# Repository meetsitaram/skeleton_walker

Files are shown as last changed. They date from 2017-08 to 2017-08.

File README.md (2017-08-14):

# Spider Hexapod

- Body designed and 3D printed
- Leg joint lengths set based on torque limits
- Servos positions have been callibrated
- Walks by 3 leg gait
 
# First Walk
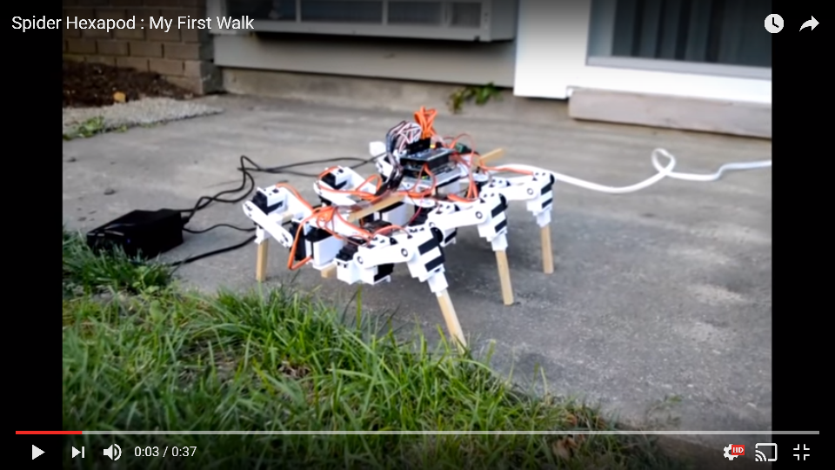
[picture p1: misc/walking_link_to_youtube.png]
First Walk (https://www.youtube.com/watch?v=spd2VwvuzV0 "Spider Hexapod : My First Walk")


# Hexapod standing up and switching on three legs:
Hexapod

## Build
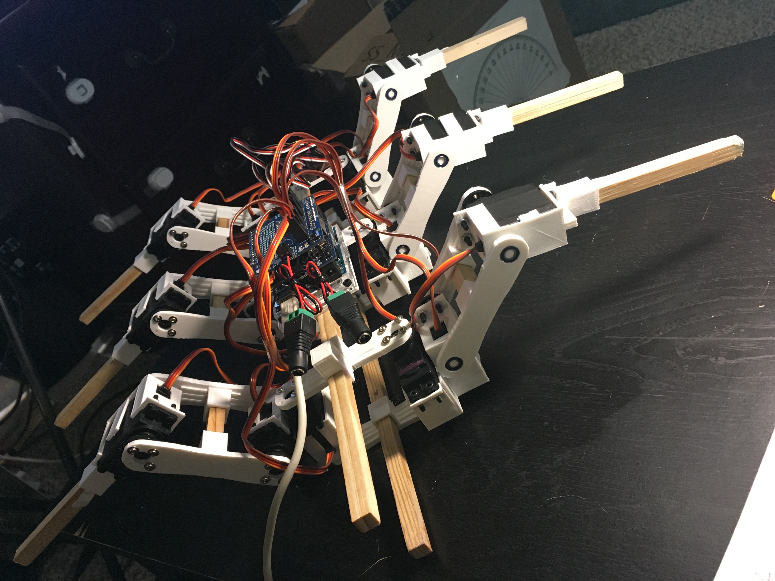
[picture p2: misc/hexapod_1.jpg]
Hexapod

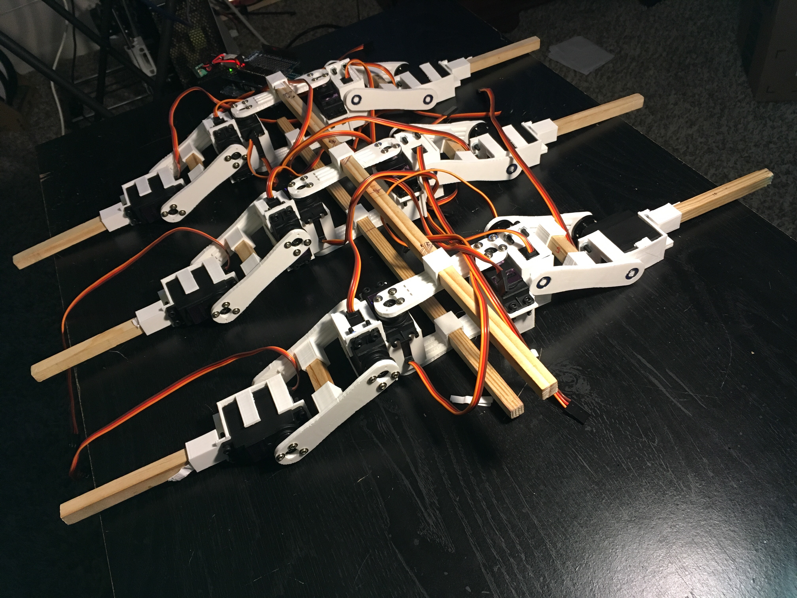
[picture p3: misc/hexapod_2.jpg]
Hexapod

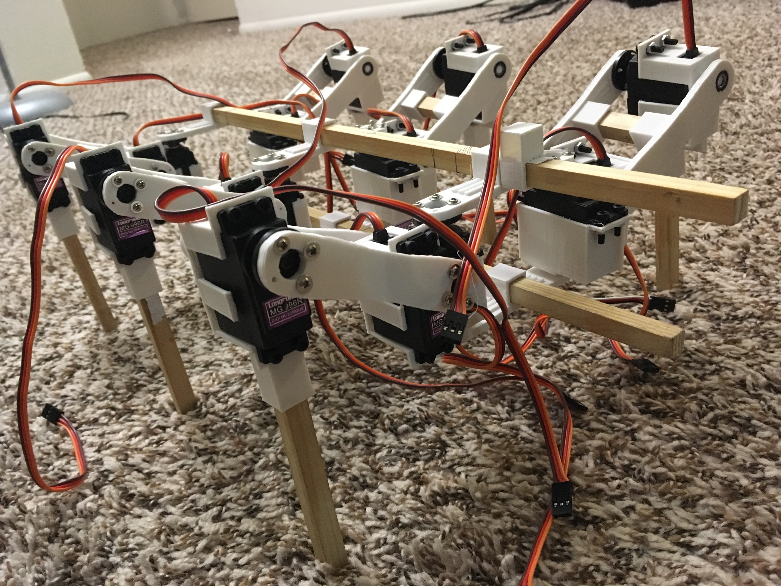
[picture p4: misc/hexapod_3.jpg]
Hexapod


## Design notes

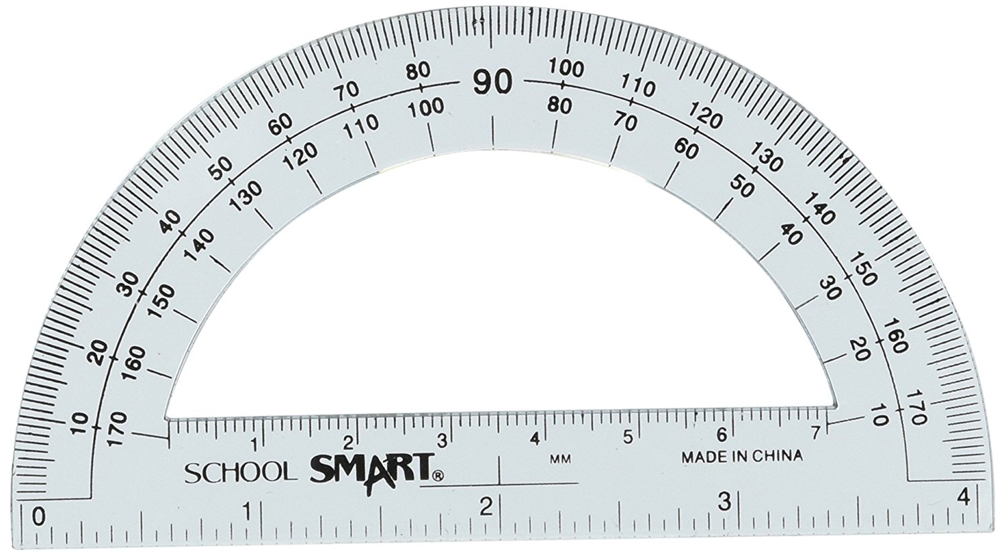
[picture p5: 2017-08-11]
docs/protractor.jpg

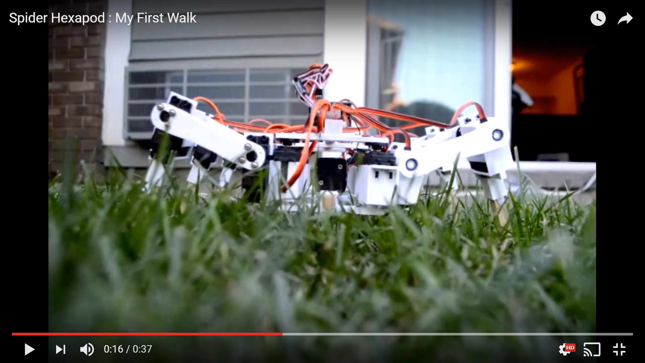
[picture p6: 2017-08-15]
misc/in_the_grass.jpg

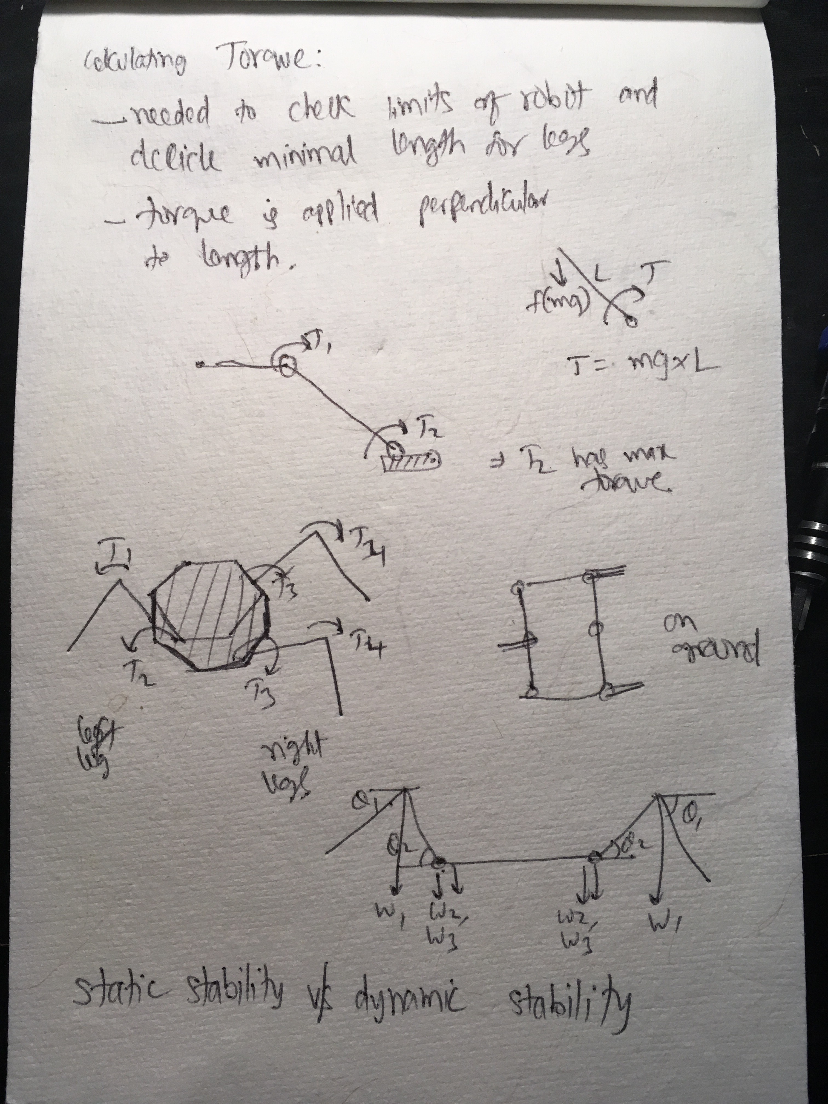
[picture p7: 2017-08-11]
misc/torque_calcs2.jpg

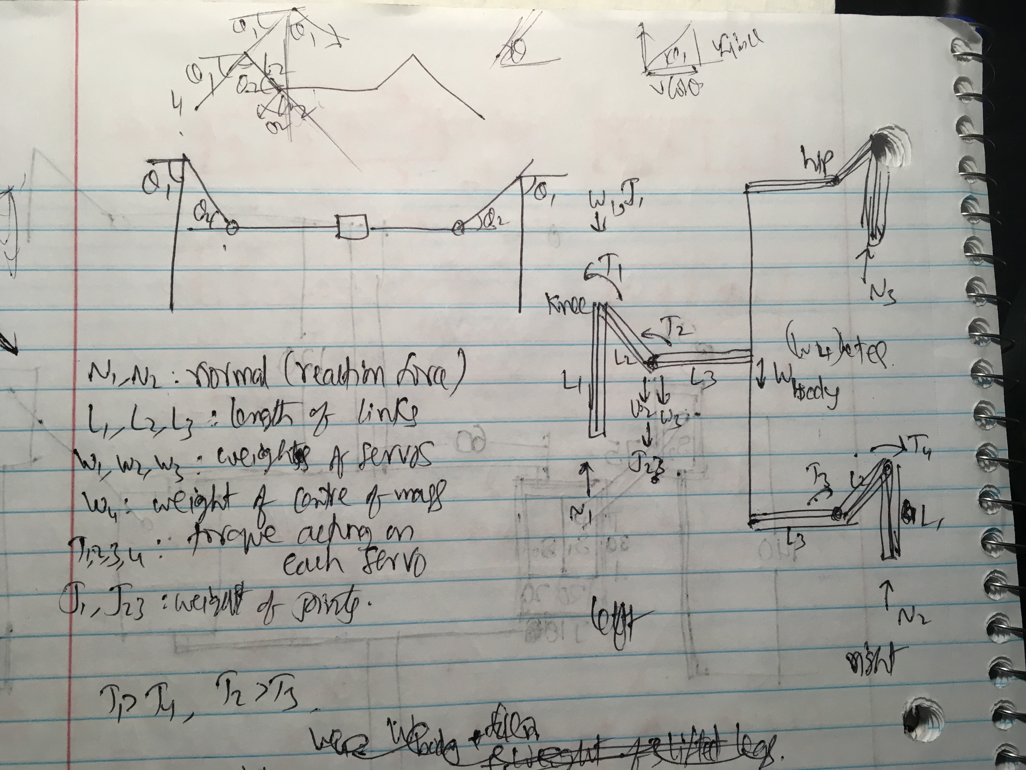
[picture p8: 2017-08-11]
misc/torque_calcs1.jpg

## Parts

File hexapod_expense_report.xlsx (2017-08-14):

$600, 150+ hours of effort and "lots" of patience
Part | Shopping Website | Amount | Qty | Total ($) | Part Description and Link
arduino | amazon | 19 | 1 | 19 | Arduino Uno R3 Microcontroller A000066 (https://www.amazon.com/gp/product/B008GRTSV6/ref=oh_aui_detailpage_o09_s00?ie=UTF8&psc=1)
servo shield | amazon | 16 | 2 | 32 | 2 of Adafruit 16-Channel 12-bit PWM/Servo Shield - I2C interface - (https://www.amazon.com/gp/product/B00I4WMOGE/ref=oh_aui_detailpage_o09_s00?ie=UTF8&psc=1)
hex bolts (100) | amazon | 17 | 1 | 17 | M3 x 12 Hex Bolt Socket Head Cap Machine Screws Black 100 Pcs (https://www.amazon.com/gp/product/B00W97N9X2/ref=oh_aui_detailpage_o03_s00?ie=UTF8&psc=1)
hex nut (100) | amazon | 5 | 1 | 5 | 100Pcs M3 3mm Female Thread Hex Metal Nut Fastener Silver Tone (https://www.amazon.com/gp/product/B00GYS1SXU/ref=oh_aui_detailpage_o02_s00?ie=UTF8&psc=1)
stackable headers | amazon | 7 | 1 | 7 | 2 of Arduino Stackable Header Kit - R3 (https://www.amazon.com/gp/product/B00PCCWEJG/ref=oh_aui_detailpage_o00_s00?ie=UTF8&psc=1)
right angle headers | amazon | 6 | 1 | 6 | Adafruit 3x4 Right Angle Male Header - 4 pack [ADA816] (https://www.amazon.com/gp/product/B00NAY2894/ref=oh_aui_detailpage_o09_s00?ie=UTF8&psc=1)
ball bearings | amazon | 10 | 2 | 20 | Traxxas 5116 5x11x4mm Replacement Precision Ball Bearings MR115-2RSBU (10) (https://www.amazon.com/gp/product/B00Y5W3JYS/ref=oh_aui_detailpage_o04_s00?ie=UTF8&psc=1)
servos (10x) | amazon | 47 | 2 | 94 | Longruner 10 x MG996R Metal Gear Torque Digital Servo Motor For RC Model Car Boat Helicopter LKY62 (https://www.amazon.com/gp/product/B01MTW06IU/ref=oh_aui_detailpage_o00_s00?ie=UTF8&psc=1)
servo extension wire (10) | amazon | 8 | 2 | 16 | 2 of Hobbypark 15cm Male to Female Servo Extension Lead Wire Cable for KK MWC Control Board RC Parts (Pack of 10) (https://www.amazon.com/gp/product/B01FLHLKZ0/ref=oh_aui_detailpage_o08_s00?ie=UTF8&psc=1)
DIY anet a8 3d printer | gearbest | 170 | 1 | 170 | Anet A8 Desktop 3D Printer Prusa i3 DIY Kit (http://www.gearbest.com/3d-printers-3d-printer-kits/pp_343643.html)
pla plastic | amazon | 22 | 1 | 22 | HATCHBOX 3D PLA-1KG1.75-WHT PLA 3D Printer Filament, Dimensional Accuracy +/- 0.05 mm, 1 kg Spool, 1.75 mm, White (https://www.amazon.com/gp/product/B00J0GMMP6/ref=oh_aui_detailpage_o01_s00?ie=UTF8&psc=1)
spool stable | amazon | 9 | 1 | 9 | Anycubic 1 Spool Stable Acrylic 3D Printer Filament Tabletop Mount Rack (https://www.amazon.com/gp/product/B019TRKDTC/ref=oh_aui_detailpage_o01_s00?ie=UTF8&psc=1)
print surface | amazon | 20 | 1 | 20 | BuildTak 3D Printing Build Surface, 6.5" x 6.5" Square, Black (Pack of 3) (https://www.amazon.com/gp/product/B00MN5X304/ref=oh_aui_detailpage_o00_s00?ie=UTF8&psc=1)
wooden dowel | home depot | 1.41 | 4 | 5.64 | Waddell 36 in. x 3/8 in. Hardwood Square Dowel (http://www.homedepot.com/p/Waddell-36-in-x-3-8-in-Hardwood-Square-Dowel-8306U/100534453)
hacksaw | home depot | 4 | 1 | 4 | Husky 6 in. Junior Hacksaw (http://www.homedepot.com/p/Husky-6-in-Junior-Hacksaw-122JHSC/204748808)
Clamp | home depot | 5 | 2 | 10 | BESSEY 4 in. x 2 in. Bar Clamp (http://www.homedepot.com/p/BESSEY-4-in-x-2-in-Bar-Clamp-LM2-004/204957893)
screw driver set | amazon | 14 | 1 | 14 | Oria 58-in-1 Precision Screwdriver Set with 54 Magnetic Bits for all Electronics Devices
soldering kit | amazon | 33 | 1 | 33 | Sywon Full Set 60W 110V Electric Soldering Iron Kit with Adjustable Temperature Welding Iron, 5pcs Tips, Desoldering Pump, 2pcs Tweezers, Tin Wire Tube, Stand and 6pcs Aid Tools in PU Carry Bag (https://www.amazon.com/gp/product/B01E1ISGH0/ref=oh_aui_detailpage_o04_s01?ie=UTF8&psc=1)
Multimeter | amazon | 19 | 1 | 19 | 2 of INNOVA 3320 Auto-Ranging Digital Multimeter (https://www.amazon.com/gp/product/B000EVYGZA/ref=oh_aui_detailpage_o05_s00?ie=UTF8&psc=1)
desoldering wick | amazon | 4 | 1 | 4 | Aven 17542 Desoldering Wick, 2.5mm Width, 5' Length (https://www.amazon.com/gp/product/B003E48ERU/ref=oh_aui_detailpage_o05_s00?ie=UTF8&psc=1)
solder wire | amazon | 9 | 1 | 9 | Sywon 60-40 Rosin Core Spool Solder Wire 0.039’’ 0.11lb (https://www.amazon.com/gp/product/B01LVTTL9E/ref=oh_aui_detailpage_o04_s01?ie=UTF8&psc=1)
6v battery pack | amazon | 11 | 1 | 11 | Tenergy 6V 2000mAh NiMH RX Battery Packs with Hitec Connector for Model Airplanes, RC Aircrafts, and Walking Robot (https://www.amazon.com/gp/product/B001BCOWLY/ref=oh_aui_detailpage_o00_s00?ie=UTF8&psc=1)
6v battery charger | amazon | 16 | 1 | 16 | Tenergy 6V-12V Universal Battery Pack Charger for NiMH NiCd RC Car Batteries (https://www.amazon.com/gp/product/B003MXMJX8/ref=oh_aui_detailpage_o00_s00?ie=UTF8&psc=1)
power plug | amazon | 7 | 1 | 7 | OdiySurveil(TM) 5Pairs 2.1mm x 5.5mm Female Male DC Power Plug Terminal Adapter for CCTV Cameras (https://www.amazon.com/gp/product/B00W058HHQ/ref=oh_aui_detailpage_o01_s00?ie=UTF8&psc=1)
Tool Kit | home depot | 14 | 1 | 14 | Stalwart Multipurpose Car and Office Black Tool Kit (15-Piece) (http://www.homedepot.com/p/Stalwart-Multipurpose-Car-and-Office-Black-Tool-Kit-15-Piece-75-HT015/206531732)
 |  | total |  | 583.64
 |  | total - printer |  | 413.64

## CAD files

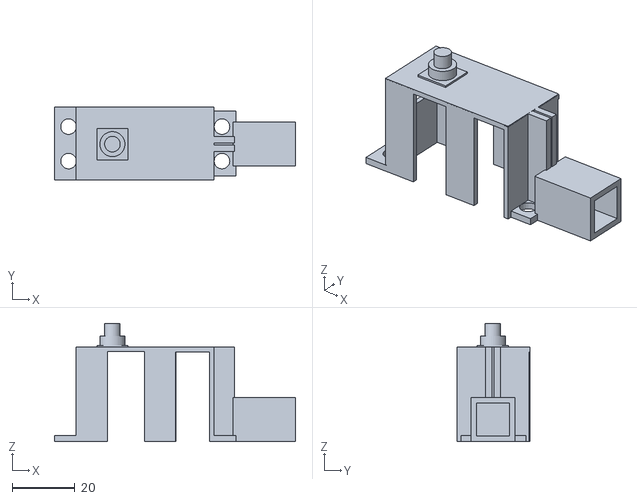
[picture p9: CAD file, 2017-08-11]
print3D/Clamp n Hold V2.stl
77.0 x 23.4 x 37.7

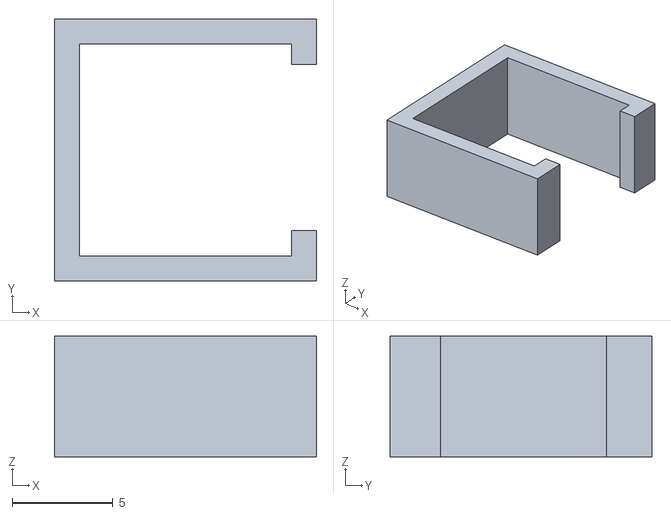
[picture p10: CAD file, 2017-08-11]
print3D/uno_support_clip.stl
13.0 x 13.0 x 6.00

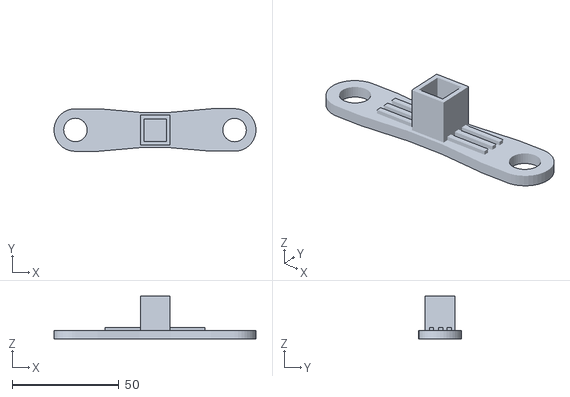
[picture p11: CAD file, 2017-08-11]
print3D/Leg Joint Th_b.stl
94.8 x 20.1 x 20.0

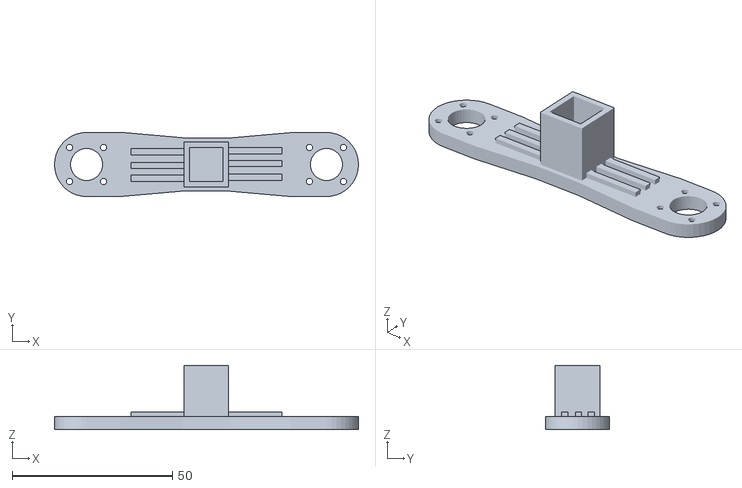
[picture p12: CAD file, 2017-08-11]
print3D/Leg Joint Th_a.stl
94.8 x 20.0 x 20.0

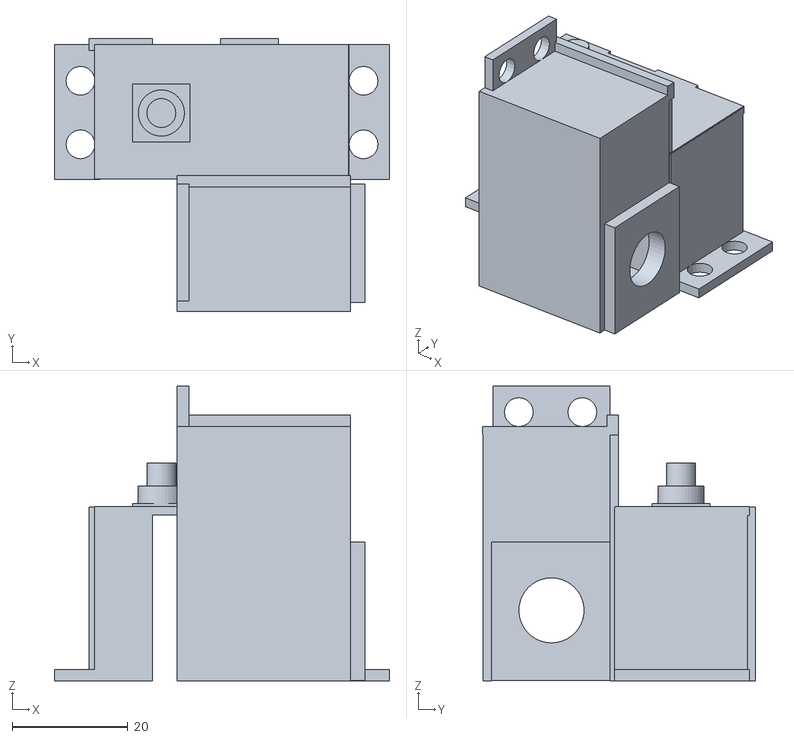
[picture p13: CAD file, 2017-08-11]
print3D/Servo Servo Clamp V4.1.stl
58.0 x 47.2 x 51.0

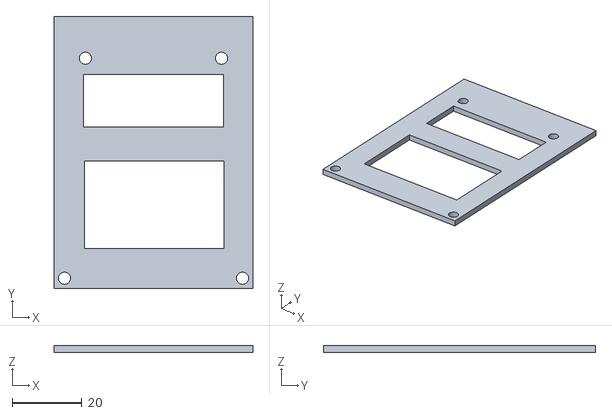
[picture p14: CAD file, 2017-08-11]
print3D/uno_support.stl
57.0 x 78.0 x 2.00

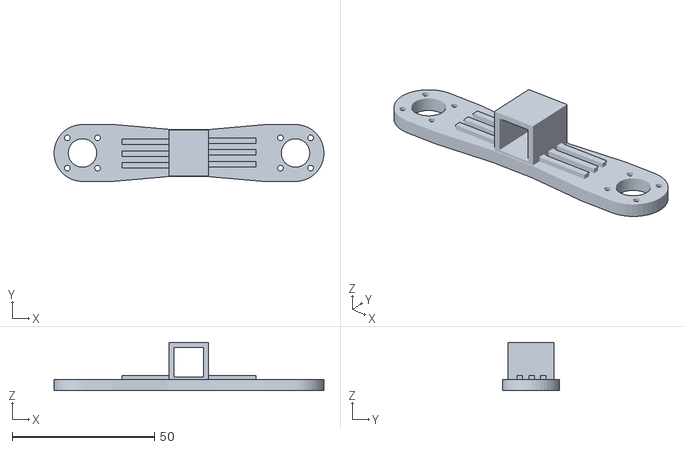
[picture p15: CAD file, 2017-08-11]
print3D/Frame Joint a.stl
94.8 x 20.0 x 17.0

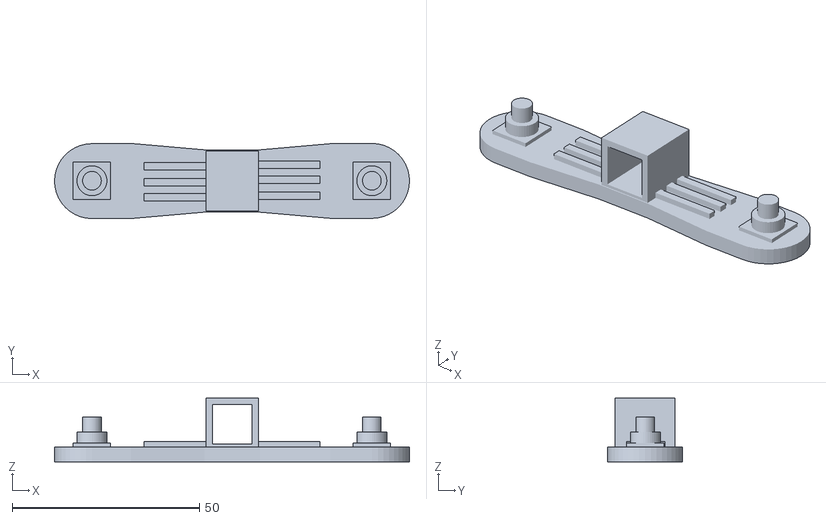
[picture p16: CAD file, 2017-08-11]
print3D/Frame Joint b.stl
94.8 x 20.1 x 17.0

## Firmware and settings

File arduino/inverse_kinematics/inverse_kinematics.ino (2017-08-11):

/*************************************************** 
  This is an example for our Adafruit 16-channel PWM & Servo driver
  Servo test - this will drive 16 servos, one after the other

  Pick one up today in the adafruit shop!
  ------> http://www.adafruit.com/products/815

  These displays use I2C to communicate, 2 pins are required to  
  interface. For Arduino UNOs, thats SCL -> Analog 5, SDA -> Analog 4

  Adafruit invests time and resources providing this open source code, 
  please support Adafruit and open-source hardware by purchasing 
  products from Adafruit!

  Written by Limor Fried/Ladyada for Adafruit Industries.  
  BSD license, all text above must be included in any redistribution
 ****************************************************/

#include <Wire.h>
#include <Adafruit_PWMServoDriver.h>
#include <math.h>

Adafruit_PWMServoDriver pwm = Adafruit_PWMServoDriver(0x40);
Adafruit_PWMServoDriver pwm2 = Adafruit_PWMServoDriver(0x41);

const double femur = 14.0; // in cm
const double tibia = 20.0;
const double coxa = 3.0; 
double Z_OFFSET = 0.0;

const int L_MIN = 15;
const int L_MAX = 12;


const int servoN10 = 0;
const int servoN10Min = 105;
const int servoN10Max = 480;
const int sheildN10 = 0;
const int initThetaN10 = 90;

const int servoN11 = 1;
const int servoN11Min = 85;
const int servoN11Max = 440;
const int sheildN11 = 0;
const int initThetaN11 = 0;
const int thetaOffsetN11 = 15;

const int servoN12 = 2;
const int servoN12Min = 95;
const int servoN12Max = 450;
const int sheildN12 = 0;
const int initThetaN12 = 0;
const int thetaN12Skew = 45.0; // servo's 0 pos is set at 45 degree angle

double getAlpha(double h, double f, double servoLift) {
  double L1 = sqrt(pow(h,2)+ pow(f,2));
  double z = Z_OFFSET + servoLift;
  double L = sqrt(pow(z,2) + pow(L1-coxa,2)); // L is radial dist from servo 2
                                                              // L1 is horizontal distance from center
  double alpha1 = acos(z/L);
  double alpha2 = acos( (pow(femur,2) + pow(L,2) - pow(tibia,2)) / (2.0*femur*L) );

  double alpha = 180*(alpha1 + alpha2) / M_PI;
  if (alpha == NAN)  {
    return 0;
  }
  return alpha;
}

double getBeta(double h, double f, double servoLift) {
  double L1 = sqrt(pow(h,2)+ pow(f,2));
  double z = Z_OFFSET + servoLift;
  double L = sqrt(pow(z,2) + pow(L1-coxa,2)); // L is radial dist from servo 2
                                                              // L1 is horizontal distance from center  
  if (L > femur + tibia) {
    return 0;
  }
  Serial.print("in beta, l:"); Serial.println(L);
  double beta = (180.0/M_PI)*acos( ( pow(femur,2) + pow(tibia, 2) - pow(L,2) )/(2.0*femur*tibia) );
  return beta;
}

double getGamma(double h, double f) {
  double L1 = sqrt(pow(h,2)+ pow(f,2));

  double gamma = 180.0*(acos( h / L1)) / M_PI;
  Serial.print("gamma val:"); Serial.println(gamma);
  if (gamma == NAN)  {
    return 90;
  }

  if(gamma > 180 || gamma < 0) {
    return 90;
  }

  if(f < 0) {
    gamma = 0 - gamma;
  }
  return gamma;
}


void setServoPosition(int servoNum, int theta) {

  if (theta < 0 || theta > 180) {
    Serial.println("invalid theta:" + theta);
    return;
  }

  int shieldNum = 0;
  int pos0 = -1;
  int pos180 = -1;
  int thetaOffset = 0.0;
  switch(servoNum) {
    case servoN10:
      pos0 = servoN10Min;
      pos180 = servoN10Max;
      shieldNum = 0;
      break;  
    case servoN11:
      pos0 = servoN11Min;
      pos180 = servoN11Max;
      thetaOffset = 15;
      shieldNum = 0;
      break;  
    case servoN12:
      pos0 = servoN12Min;
      pos180 = servoN12Max;
      shieldNum = 0;
      break;  

    default:
      Serial.println("invalid servo:" + servoNum );
      return;                                
  }

  if (pos0 < 0 || pos180 < 0) {
    Serial.println("invalid servo:" + servoNum);
    return;
  }

  if (theta < thetaOffset) {
    theta = thetaOffset;
  }
  double pulseLength = map(theta, 0, 180, pos0, pos180);
  if(shieldNum == 0) {
    pwm.setPWM(servoNum, 0, pulseLength);
  } else {
    pwm2.setPWM(servoNum, 0, pulseLength);
  }
  
}

void setup() {
  
  
  Serial.begin(9600);
  Serial.println("16 channel, dual shield, Servo test!");

  pwm.begin();
  pwm.setPWMFreq(50); 
  

  yield();
}

void setArmPosition(double h, double f, double servoLift) {
  double gamma = getGamma(h, f);
  Serial.print("gamma:"); Serial.println(gamma);
  Serial.print("90 - gamma:"); Serial.println(90 - gamma);
  
  double alpha = getAlpha(h, f, servoLift);
  Serial.print("180 - alpha:"); Serial.println(180 - alpha);

  double beta = getBeta(h, f, servoLift);
  Serial.print("beta:"); Serial.println(beta);

  setServoPosition(servoN10, 90 - gamma);
  setServoPosition(servoN11, 180 - alpha);
  setServoPosition(servoN12, beta - 45);  
}

void testMoveStraight() {
  double h = 20;  //horizontal distance from center
  //double f = -10; // forward or backward distance
  int servoLift = 8; // height of center above ground

  for(double f = 20.0; f >= -20; f = f-1) {
    setArmPosition(h, f, servoLift);
    delay(100);
  }
  
  for(double f = -20.0; f <= 20; f = f+1) {
    setArmPosition(h, f, servoLift);
    delay(100);
  }  
}

void testMoveSideways() {
  double f = 0;  //horizontal distance from center
  int servoLift = 8; // height of center above ground

  for(double h = 30.0; h >= 15; h = h-1) {
    setArmPosition(h, f, servoLift);
    delay(100);
  }
  
  for(double h = 15.0; h <= 30; h = h+1) {
    setArmPosition(h, f, servoLift);
    delay(100);
  }  
}


void testMoveUpwards() {
  double f = 0;  //horizontal distance from center
  double h = 25;
  int servoLift = 8; // height of center above ground

  for(double servoLift = 8.0; servoLift >= -20; servoLift = servoLift-1) {
    setArmPosition(h, f, servoLift);
    delay(1000);
  }
  
  for(double servoLift = -20.0; servoLift <= 8; servoLift = servoLift+1) {
    setArmPosition(h, f, servoLift);
    delay(1000);
  }  
}

void loop() {

    testMoveStraight();
    testMoveSideways();
    //testMoveUpwards();

  

  delay(4000);

}

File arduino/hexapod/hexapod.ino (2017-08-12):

//
// Hexapod Code
//

#include <math.h>
#include "core_servo_utils.h"
#include "hexapod.h"

#include "walking_style.h"

WalkingStyle style;
bool ENABLE_DEBUG = false;

void setup() {
  
  if(ENABLE_DEBUG) {
    Serial.begin(9600);
  }
  Serial.println("Waking up 18 servo spider hexapod!");

  setupPwm();

  setInitialServoPositions();

  delay(5000);
  yield();
}

void loop() {

  // setServoPosition(sn60_pin, 60);
  // delay(5000);
  // setServoPosition(sn60_pin, 90);
  // delay(5000);
  // setServoPosition(sn60_pin, 120);
  // delay(10000);
  style.go();
  
}

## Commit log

2017-07-22 caliberated and connected servos
    [Back Bone Joint.stl, Clamp n Hold.stl, Servo - Servo Clamp.stl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]
2017-08-11 hexapod designed, built and calibrated
    [Back Bone Joint.stl, Clamp n Hold.stl, Frame Joint a.stl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]
2017-08-11 add missing .stl file
    [Clamp n Hold V2.stl]
2017-08-14 First Walk
    [hexapod_expense_report.xlsx]
